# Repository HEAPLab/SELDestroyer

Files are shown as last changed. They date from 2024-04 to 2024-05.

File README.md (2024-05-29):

This README is a WIP.

# SEL Destroyer
This repository contains the hardware, firmware and software files of the
**SEL Destroyer** board, which is an electronic device to detect and destroy
the Single Event Latches (SELs) happening during SEE testing of electronic
components (radiation testing, laser-based testing, etc.).

The SEL destroyer can be also used as a normal voltage, current, or power monitoring device.

## Features
...

## Repository structure
- The `hardware` directory contains the KiCad files
  - See the hardware readme (WIP)
- The `firmware` directory contains the MPLAB X project (XC8 compiler) to program the PIC microcontroller
  - See the firmware readme (WIP)
- The `software` directory contains the host software (PC-side)
  - Check the software [README](software/README.md)

## License
MIT license, see the [LICENSE](LICENSE) file.

## Acknowledgments

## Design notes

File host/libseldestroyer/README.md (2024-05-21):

## libseldestroyer

TODO

### Thread safety
This library is partially thread-safe:
- You can call any function from different thread with the exception of...
- Calling the same function from two threads may bring to unexpected de-synchronization of the value. For instance, two concurrent access to V/I function may result in returing the same values for both calls

TODO

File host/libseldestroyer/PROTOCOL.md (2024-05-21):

Protocol description
====================

All the messages (in both directions) begin with the character `$`. If any
error occurs, each side must wait for the following `$` character.
All the commands are terminated with `\n` character.

Device -> Host
--------------
- `$P`: Pong
- `$V,SXXXXX`: voltage reading, XXXXX in mV
- `$I,SXXXXX`: current reading, XXXXX in mA
- `$N,+XXX`: number of SELs detected
- `$S`: SEL detected (XXXXX = max current in mA)
- `$CL,XXXXX`: current limiter set value, XXXXX in mA
- `$CH,XXXXX`: current limiter hold time value, XXXXX in 100-us (i.e., XXXXXX=1
  means 100us, XXXXX=20000 means 2 seconds. Max allowed value 4 seconds)
- `$CM,XXXXX`: average mode
- `$CO,X`: current output status: 0 - always OFF, 1 - always ON, A - auto
- `$E`: protocol error / overflow
- `$*`: done (any request)

Host -> Device
--------------
- `$P`: Ping
- `$A`: Ask for V/I instant readings
- `$N`: Ask for number of SELs
- `$R`: Reset number of SELs
- `$?`: Ask for current configs
- `$CL,XXXXX`: Configure limiter set value,  XXXXX in mA
- `$CH,XXXXX`: Configure limiter hold time value in 100-us (i.e., XXXXXX=1
  means 100us, XXXXXX=100000 means 10 seconds)
- `$CM,X`: Configure average mode of the INA233
- `$CO,X`:  Set output mode: 0 - always OFF, 1 - always ON, A - auto

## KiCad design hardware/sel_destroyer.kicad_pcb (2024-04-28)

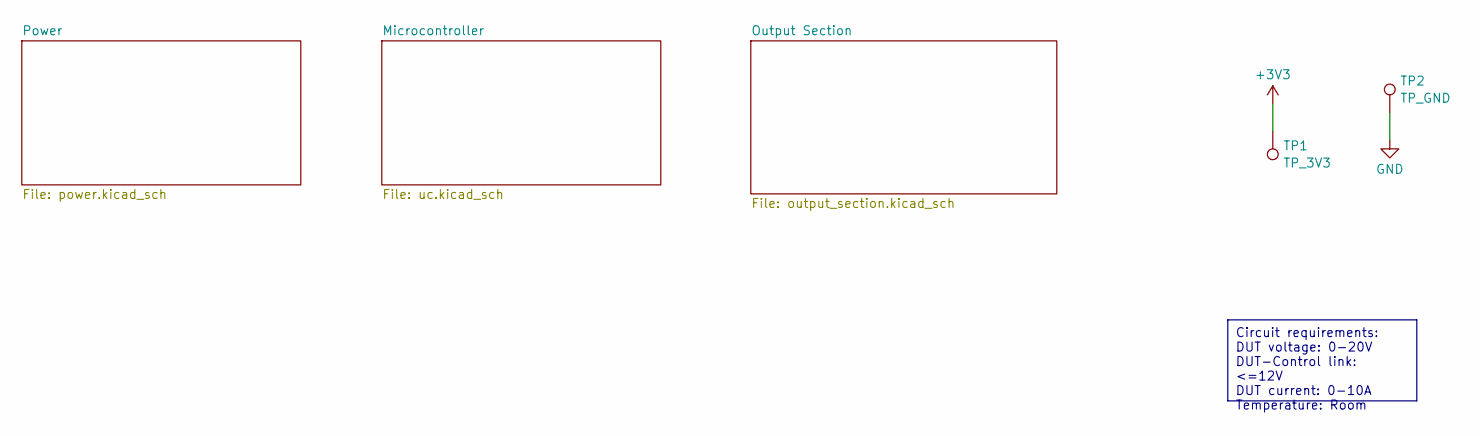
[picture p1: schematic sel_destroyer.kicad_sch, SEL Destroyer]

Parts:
TP1: TP_3V3; TestPoint_Loop_D1.80mm_Drill1.0mm_Beaded
TP2: TP_GND; TestPoint_Loop_D1.80mm_Drill1.0mm_Beaded

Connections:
+3V3: TP1.1; also elsewhere on the board
GND: TP2.1; also elsewhere on the board

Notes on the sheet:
Circuit requirements: DUT voltage: 0-20V DUT-Control link: <=12V DUT current: 0-10A Temperature: Room

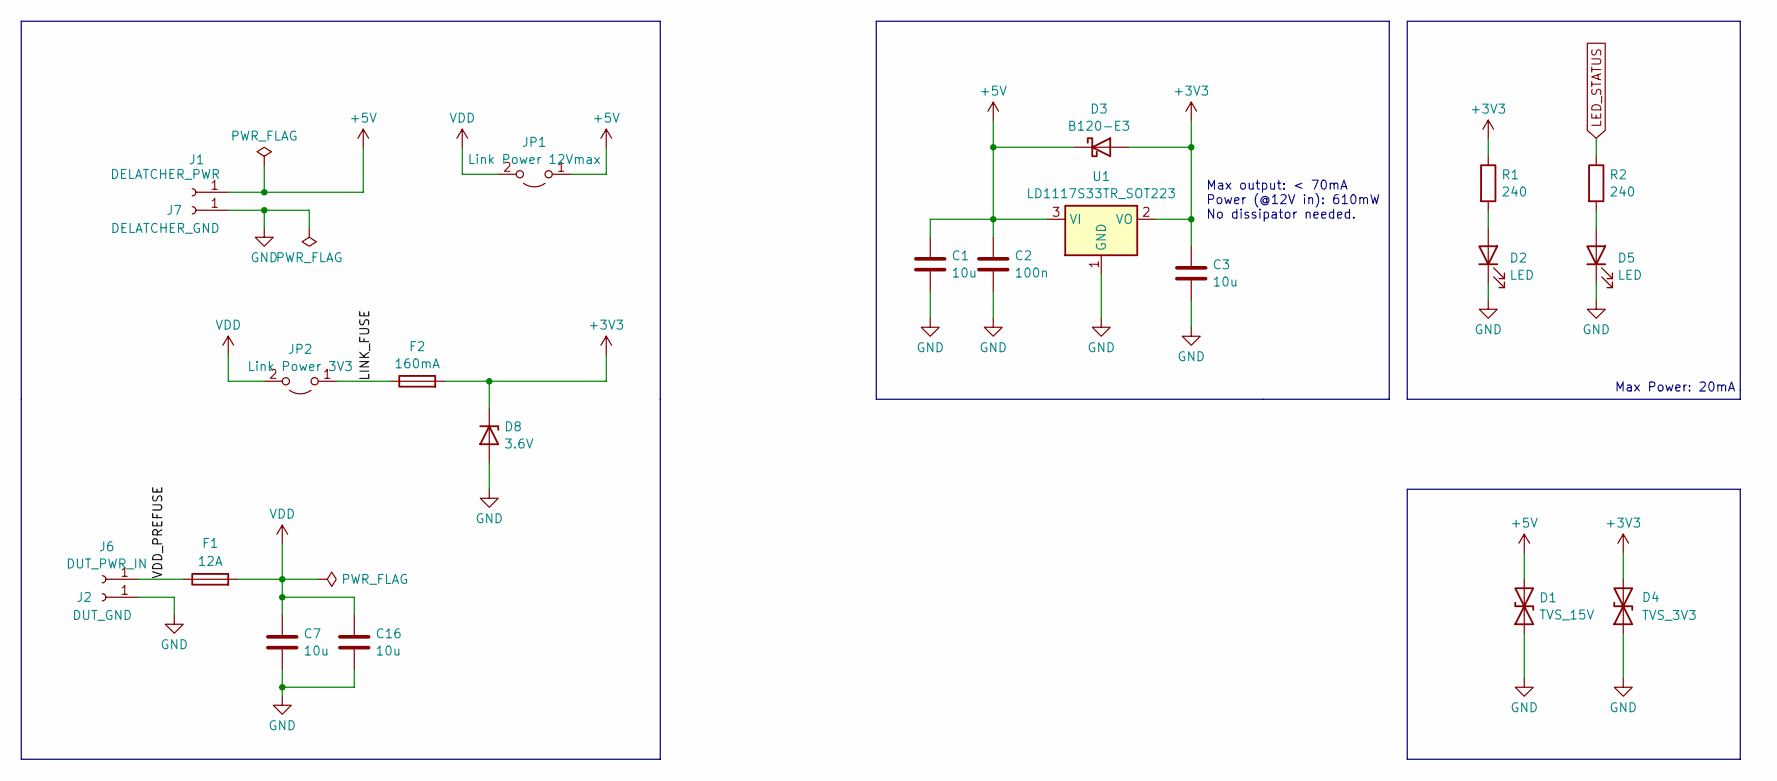
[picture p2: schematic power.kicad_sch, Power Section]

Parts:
C1, C3: 10u; C_0805_2012Metric_Pad1.18x1.45mm_HandSolder
C2: 100n; C_0805_2012Metric_Pad1.18x1.45mm_HandSolder
C7, C16: 10u; C_1206_3216Metric_Pad1.33x1.80mm_HandSolder
D1: TVS_15V; D_0603_1608Metric_Pad1.05x0.95mm_HandSolder
D2, D5: LED; LED_0805_2012Metric_Pad1.15x1.40mm_HandSolder
D3: B120-E3; D_SMA
D4: TVS_3V3; D_0603_1608Metric_Pad1.05x0.95mm_HandSolder
D8: 3.6V; D_SMB_Handsoldering
F1: 12A; Fuse_1206_3216Metric_Pad1.42x1.75mm_HandSolder
F2: 160mA; Fuse_1206_3216Metric_Pad1.42x1.75mm_HandSolder
J1: DELATCHER_PWR; CT3151
J2: DUT_GND; CT3151
J6: DUT_PWR_IN; CT3151
J7: DELATCHER_GND; CT3151
JP1: Link Power 12Vmax; PinHeader_1x02_P2.54mm_Vertical
JP2: Link Power 3V3; PinHeader_1x02_P2.54mm_Vertical
R1, R2: 240; R_0805_2012Metric_Pad1.20x1.40mm_HandSolder
U1: LD1117S33TR_SOT223; SOT-223-3_TabPin2

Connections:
+3V3: C3.1, D3.2 (A), D4.2 (A2), D8.1 (K), F2.2, R1.1, U1.2 (VO); also elsewhere on the board
+5V: C1.1, C2.1, D1.2 (A2), D3.1 (K), J1.1, JP1.1 (A), U1.3 (VI)
/Power/LINK_FUSE: F2.1, JP2.1 (A)
/Power/VDD_PREFUSE: F1.1, J6.1
GND: C1.2, C2.2, C3.2, C7.2, C16.2, D1.1 (A1), D2.1 (K), D4.1 (A1), D5.1 (K), D8.2 (A), J2.1, J7.1, U1.1 (GND); also elsewhere on the board
LED_STATUS: R2.1; also elsewhere on the board
unnamed: D2.2 (A), R1.2
unnamed: D5.2 (A), R2.2
VDD: C7.1, C16.1, F1.2, JP1.2 (B), JP2.2 (B); also elsewhere on the board

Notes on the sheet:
Max Power: 20mA
Max output: < 70mA Power (@12V in): 610mW No dissipator needed.

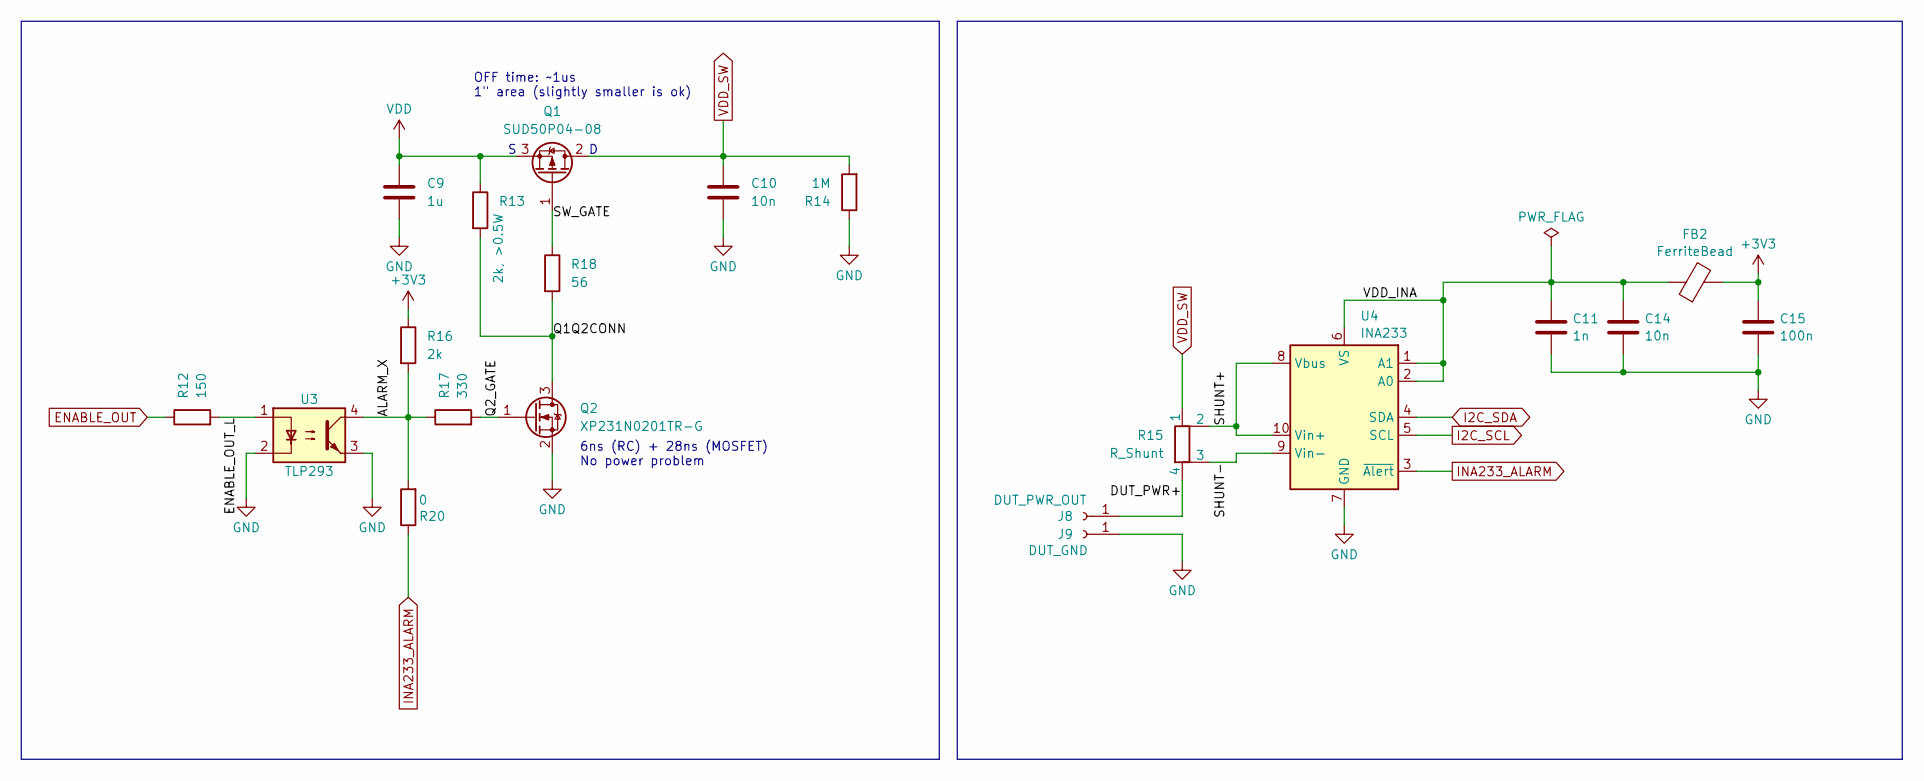
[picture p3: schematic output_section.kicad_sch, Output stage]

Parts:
C9: 1u; C_0805_2012Metric_Pad1.18x1.45mm_HandSolder
C10, C14: 10n; C_0805_2012Metric_Pad1.18x1.45mm_HandSolder
C11: 1n; C_0805_2012Metric_Pad1.18x1.45mm_HandSolder
C15: 100n; C_0805_2012Metric_Pad1.18x1.45mm_HandSolder
FB2: FerriteBead; L_0805_2012Metric_Pad1.15x1.40mm_HandSolder
J8: DUT_PWR_OUT; CT3151
J9: DUT_GND; CT3151
Q1: SUD50P04-08; TO-252-2
Q2: XP231N0201TR-G; SOT-23
R12: 150; R_0805_2012Metric_Pad1.20x1.40mm_HandSolder
R13: 2k, >0.5W; R_0805_2012Metric_Pad1.20x1.40mm_HandSolder
R14: 1M; R_0805_2012Metric_Pad1.20x1.40mm_HandSolder
R15: R_Shunt; R_Shunt_Vishay_WSK2512_6332Metric_T2.21mm
R16: 2k; R_0805_2012Metric_Pad1.20x1.40mm_HandSolder
R17: 330; R_0805_2012Metric_Pad1.20x1.40mm_HandSolder
R18: 56; R_0805_2012Metric_Pad1.20x1.40mm_HandSolder
R20: 0; R_0805_2012Metric_Pad1.20x1.40mm_HandSolder
U3: TLP293; SOIC-4_4.55x2.6mm_P1.27mm
U4: INA233; VSSOP-10_3x3mm_P0.5mm

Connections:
+3V3: C15.1, FB2.2, R16.1; also elsewhere on the board
/Output Section/DUT_PWR+: J8.1, R15.4
/Output Section/ENABLE_OUT_L: R12.2, U3.1
/Output Section/Q1Q2CONN: Q2.3 (D), R13.2, R18.2
/Output Section/Q2_GATE: Q2.1 (G), R17.2
/Output Section/SHUNT+: R15.2, U4.8 (Vbus), U4.10 (Vin+)
/Output Section/SHUNT-: R15.3, U4.9 (Vin-)
/Output Section/SW_GATE: Q1.1 (G), R18.1
/Output Section/VDD_INA: C11.1, C14.1, FB2.1, U4.1 (A1), U4.2 (A0), U4.6 (VS)
ENABLE_OUT: R12.1; also elsewhere on the board
GND: C9.2, C10.2, C11.2, C14.2, C15.2, J9.1, Q2.2 (S), R14.1, U3.2, U3.3, U4.7 (GND); also elsewhere on the board
I2C_SCL: U4.5 (SCL); also elsewhere on the board
I2C_SDA: U4.4 (SDA); also elsewhere on the board
INA233_ALARM: R20.1, U4.3 (~Alert); also elsewhere on the board
unnamed: R16.2, R17.1, R20.2, U3.4
VDD: C9.1, Q1.3 (S), R13.1; also elsewhere on the board
VDD_SW: C10.1, Q1.2 (D), R14.2, R15.1

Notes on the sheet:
OFF time: ~1us 1" area (slightly smaller is ok)
6ns (RC) + 28ns (MOSFET) No power problem

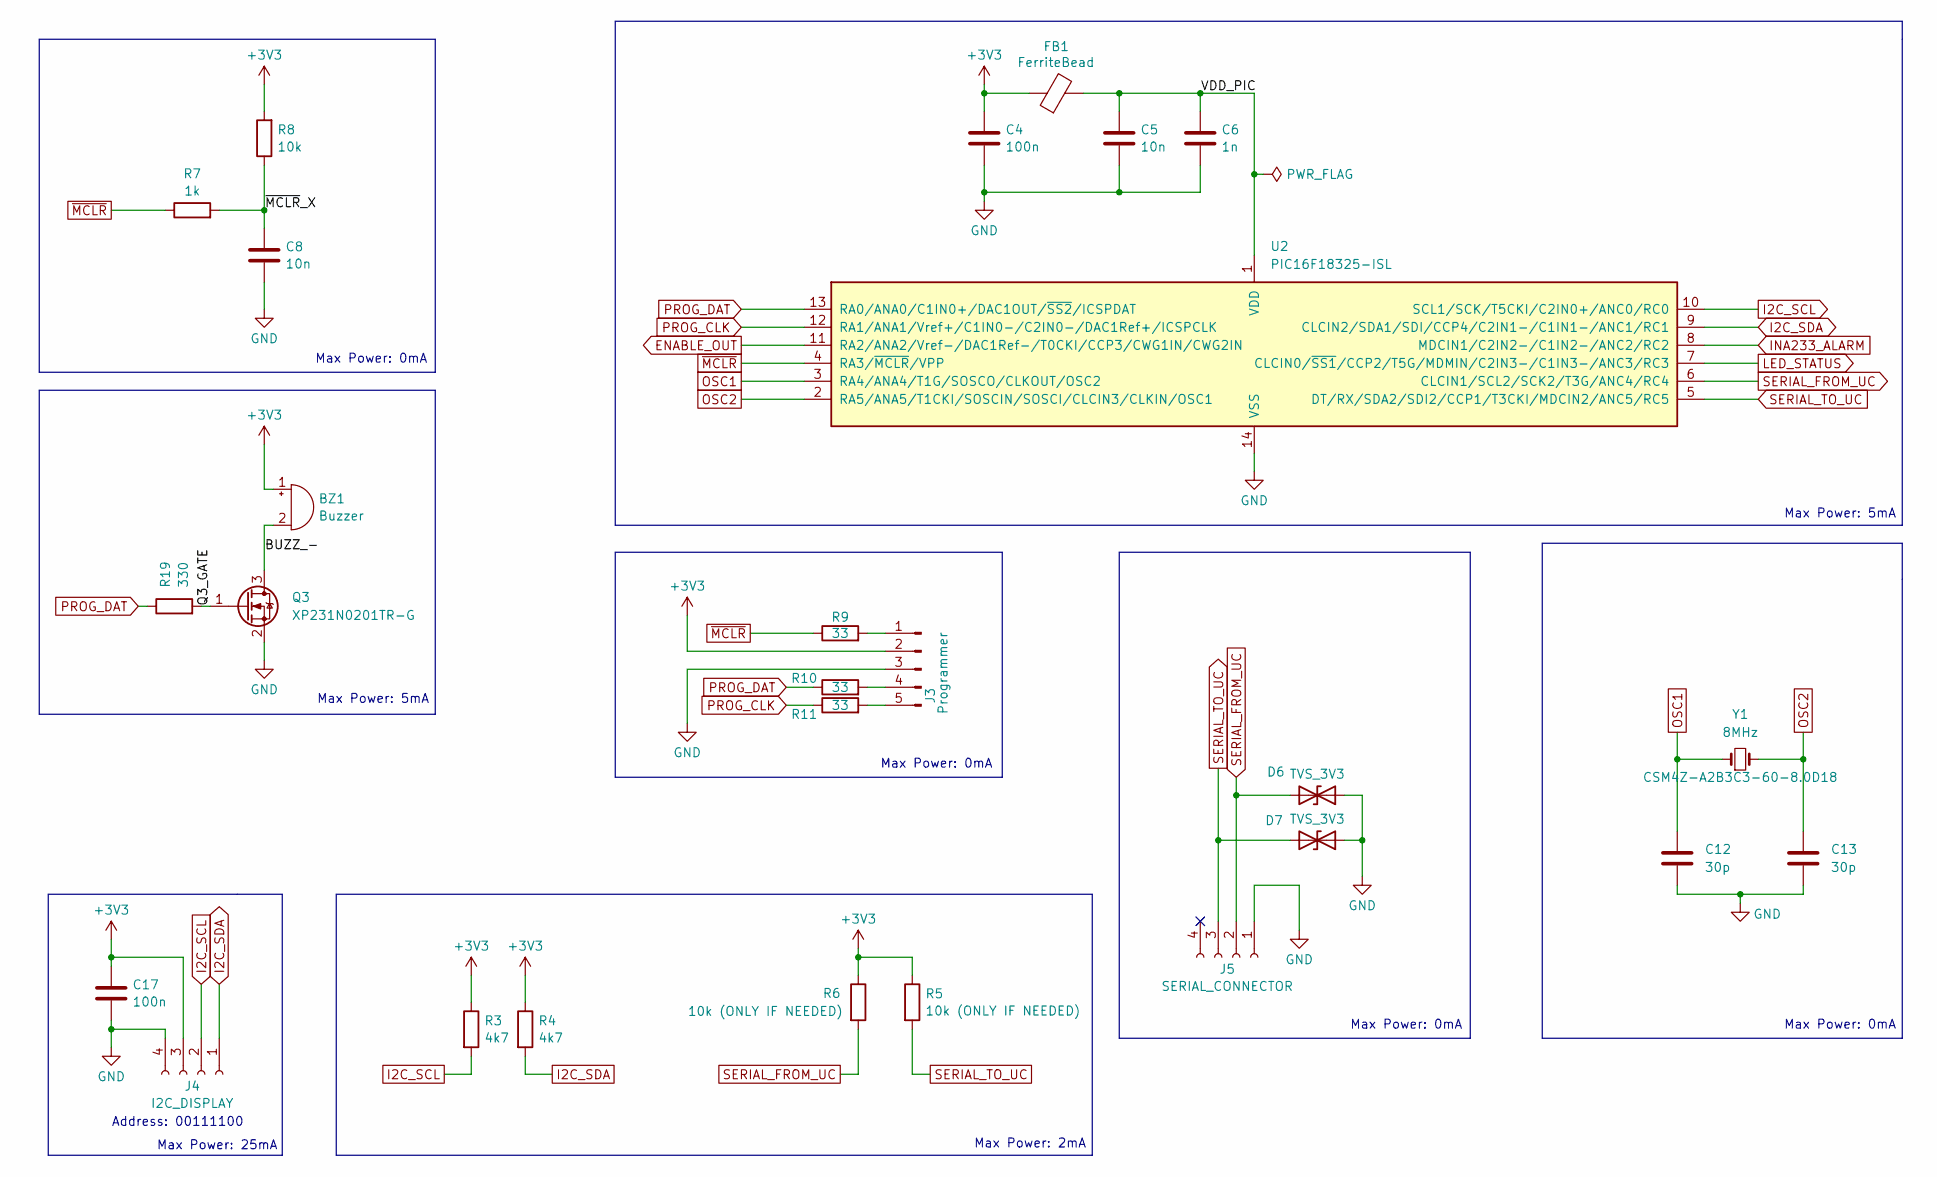
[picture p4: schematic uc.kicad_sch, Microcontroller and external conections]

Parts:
BZ1: Buzzer; Buzzer_CUI_CPT-9019S-SMT
C4, C17: 100n; C_0805_2012Metric_Pad1.18x1.45mm_HandSolder
C5, C8: 10n; C_0805_2012Metric_Pad1.18x1.45mm_HandSolder
C6: 1n; C_0805_2012Metric_Pad1.18x1.45mm_HandSolder
C12, C13: 30p; C_0805_2012Metric_Pad1.18x1.45mm_HandSolder
D6, D7: TVS_3V3; D_0603_1608Metric_Pad1.05x0.95mm_HandSolder
FB1: FerriteBead; L_0805_2012Metric_Pad1.15x1.40mm_HandSolder
J3: Programmer; PinHeader_1x05_P2.54mm_Vertical
J4: I2C_DISPLAY; PinSocket_1x04_P2.54mm_Vertical
J5: SERIAL_CONNECTOR; PinSocket_1x04_P2.54mm_Horizontal
Q3: XP231N0201TR-G; SOT-23
R3, R4: 4k7; R_0805_2012Metric_Pad1.20x1.40mm_HandSolder
R5, R6: 10k (ONLY IF NEEDED); R_0805_2012Metric_Pad1.20x1.40mm_HandSolder
R7: 1k; R_0805_2012Metric_Pad1.20x1.40mm_HandSolder
R8: 10k; R_0805_2012Metric_Pad1.20x1.40mm_HandSolder
R9, R10, R11: 33; R_0805_2012Metric_Pad1.20x1.40mm_HandSolder
R19: 330; R_0805_2012Metric_Pad1.20x1.40mm_HandSolder
U2: PIC16F18325-ISL; SOIC-14_3.9x8.7mm_P1.27mm
Y1: 8MHz; Crystal_SMD_HC49-SD

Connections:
+3V3: BZ1.1 (+), C4.1, C17.1, FB1.1, J3.2, J4.3, R3.1, R4.1, R5.1, R6.1, R8.2; also elsewhere on the board
/Microcontroller/BUZZ_-: BZ1.2 (-), Q3.3 (D)
/Microcontroller/Q3_GATE: Q3.1 (G), R19.2
/Microcontroller/VDD_PIC: C5.1, C6.1, FB1.2, U2.1 (VDD)
/Microcontroller/~MCLR_X: C8.1, R7.2, R8.1
ENABLE_OUT: U2.11 (RA2/ANA2/Vref-/DAC1Ref-/T0CKI/CCP3/CWG1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); also elsewhere on the board
GND: C4.2, C5.2, C6.2, C8.2, C12.2, C13.2, C17.2, D6.1 (A1), D7.1 (A1), J3.3, J4.4, J5.1, Q3.2 (S), U2.14 (VSS); also elsewhere on the board
I2C_SCL: J4.2, R3.2, U2.10 (SCL1/SCK/T5CKI/C2IN0+/ANC0/RC0); also elsewhere on the board
I2C_SDA: J4.1, R4.2, U2.9 (CLCIN2/SDA1/SDI/CCP4/C2IN1-/C1IN1-/ANC1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); also elsewhere on the board
INA233_ALARM: U2.8 (MDCIN1/C2IN2-/C1IN2-/ANC2/RC2); also elsewhere on the board
LED_STATUS: U2.7 (CLCIN0/~SS1/CCP2/T5G/MDMIN/C2IN3-/C1IN3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); also elsewhere on the board
unnamed: J3.1, R9.2
unnamed: J3.4, R10.2
unnamed: J3.5, R11.2
OSC1: C12.1, U2.3 (RA4/ANA4/T1G/SOSCO/CLKOUT/OSC2), Y1.1
OSC2: C13.1, U2.2 (RA5/ANA5/T1CKI/SOSCIN/SOSCI/CLCIN3/CLKI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), Y1.2
PROG_CLK: R11.1, U2.12 (RA1/ANA1/Vref+/C1IN0-/C2IN0-/DAC1Ref+/I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)
PROG_DAT: R10.1, R19.1, U2.13 (RA0/ANA0/C1IN0+/DAC1OUT/~SS2/ICSPDAT)
SERIAL_FROM_UC: D6.2 (A2), J5.2, R6.2, U2.6 (CLCIN1/SCL2/SCK2/T3G/ANC4/RC4)
SERIAL_TO_UC: D7.2 (A2), J5.3, R5.2, U2.5 (DT/RX/SDA2/SDI2/CCP1/T3CKI/MDCIN2/ANC5/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)
~MCLR: R7.1, R9.1, U2.4 (RA3/~MCLR/VPP)

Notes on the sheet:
Max Power: 2mA
Max Power: 0mA
Address: 00111100
Max Power: 5mA
Max Power: 25mA

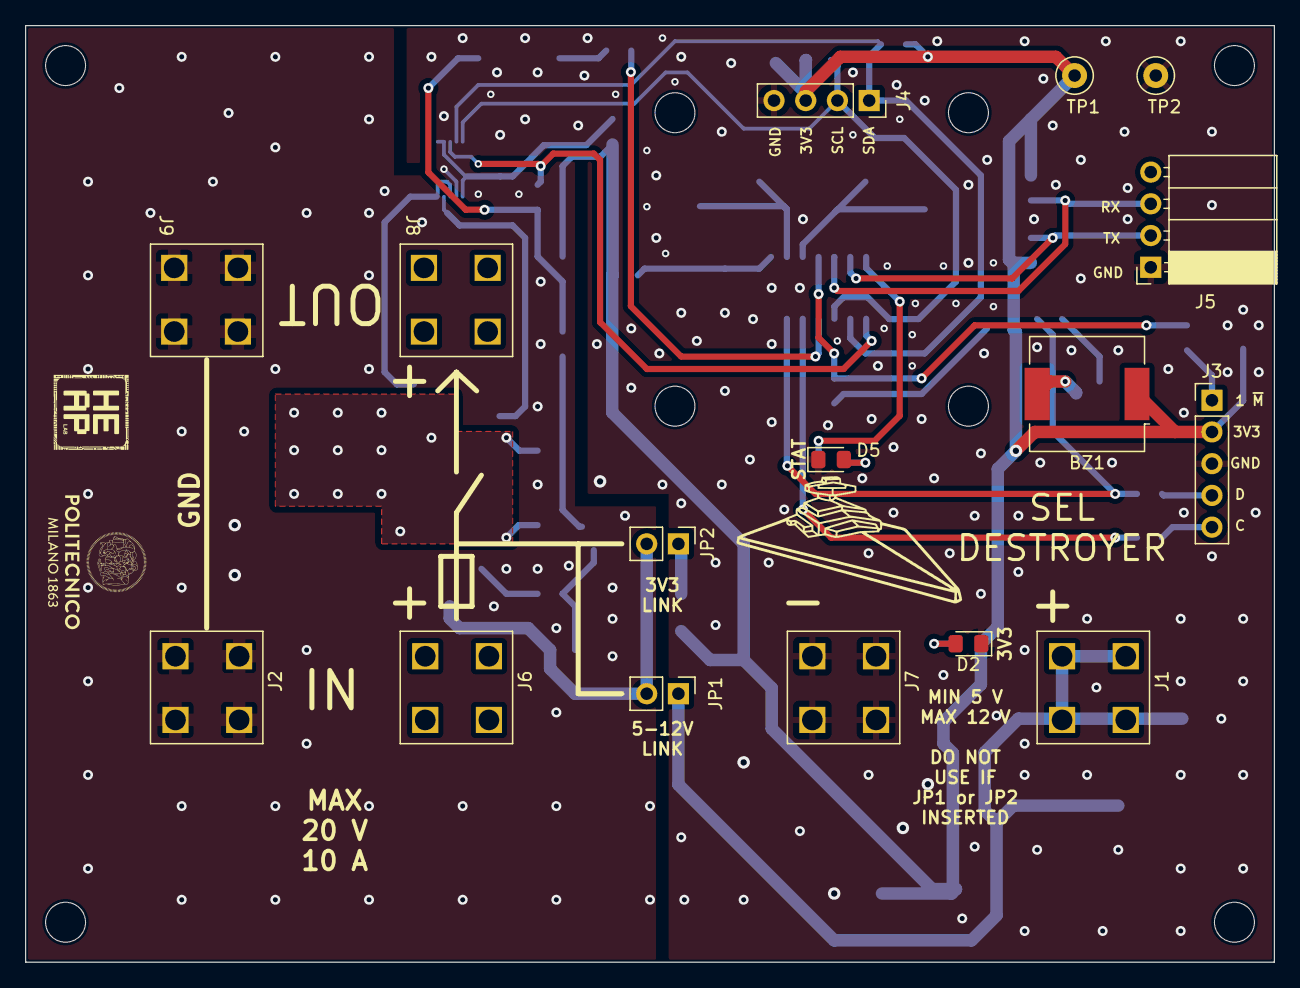
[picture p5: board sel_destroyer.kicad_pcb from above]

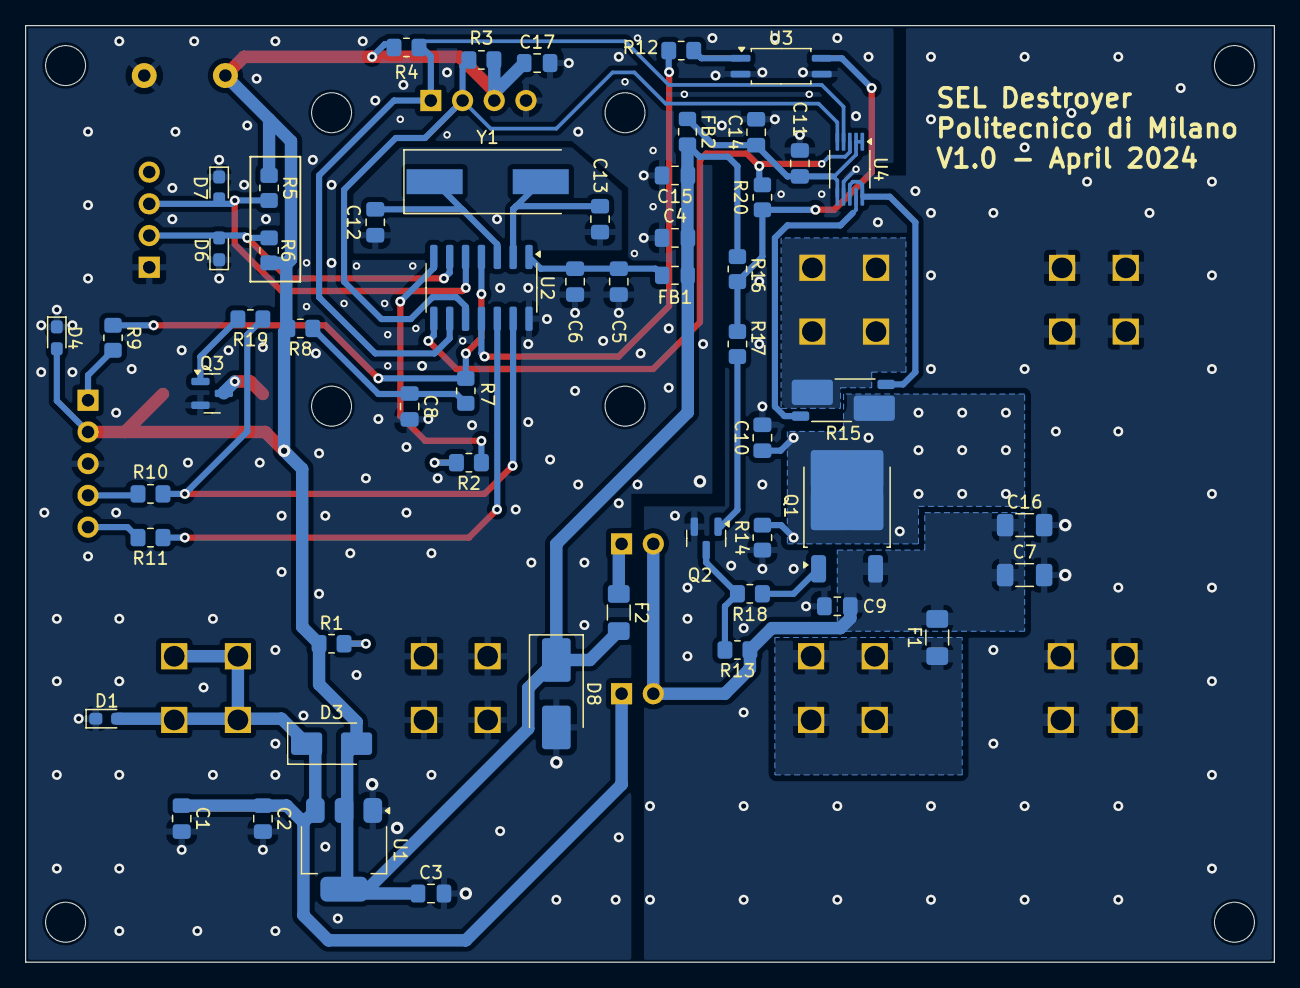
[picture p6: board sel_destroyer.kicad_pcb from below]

Board: 2 copper layers, 100.0 x 75.0 mm, 71 parts (55 on the bottom side), 37 nets.

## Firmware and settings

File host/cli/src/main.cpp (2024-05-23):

#include "libseldestroyer.h"

#include "options.hpp"

#include <chrono>
#include <memory>
#include <iostream>

static lsd_obj_t lobj;

static void ret_checker(lsd_return_val_t ret) {
    if(ret != LSD_OK) {
        std::cerr << "Error! " << std::endl
                  << "Code:    " << (int) ret << std::endl
                  << "Details: " << lsd_get_error(lobj) << std::endl;

        throw std::exception();
    }
}

static void perform_connect(const std::string &device_name) {
    lsd_return_val_t ret = lsd_connect(lobj, device_name.c_str());
    ret_checker(ret);
}

static void perform_readVI() {
    lsd_readings_t out;
    lsd_return_val_t ret = lsd_get_readings(lobj, &out);
    ret_checker(ret);
    std::cout << "Voltage (V): " << out.V << std::endl;
    std::cout << "Current (A): " << out.I << std::endl;
    std::cout << "Power   (W): " << out.V * out.I << std::endl;
}

static void perform_getSEL() {
    unsigned int out;
    lsd_return_val_t ret = lsd_get_SEL_count(lobj, &out);
    ret_checker(ret);
    std::cout << "SEL counter: " << out << std::endl;
}

static void perform_resetSEL() {
    unsigned int out;
    lsd_return_val_t ret = lsd_reset_SEL_count(lobj);
    ret_checker(ret);
    std::cout << "RESET SEL OK." << std::endl;
}

static void perform_getCONFIG() {
    lsd_config_t out;
    lsd_return_val_t ret = lsd_get_config(lobj, &out);
    ret_checker(ret);
    std::cout << "Max current              (A): " << out.sel_curr_max_A << std::endl;
    std::cout << "Hold time               (us): " << out.sel_hold_time_us << std::endl;
    std::cout << "Number of averages:           " << out.avg_num << std::endl;
    std::cout << "Voltage conversion time (us): " << out.voltage_conv_time << std::endl;
    std::cout << "Current conversion time (us): " << out.current_conv_time << std::endl;
    std::cout << "Output state:                 ";
    switch (out.output_status) {
        case LSD_OUTPUT_STATUS_OFF: std::cout  << "OFF"; break;
        case LSD_OUTPUT_STATUS_ON: std::cout   << "ON"; break;
        case LSD_OUTPUT_STATUS_AUTO: std::cout << "AUTO"; break;
        default: std::cout << "UNKONWN"; break;
    }
    std::cout << std::endl;

}

void perform_set_output(lsd_output_status_t output_state) {

    lsd_return_val_t ret = lsd_set_output(lobj, output_state);
    ret_checker(ret);

    std::cout << "Output setting updated." << std::endl;
}

void perform_set_config(std::optional<float> arg_max_I, std::optional<unsigned int> arg_hold_time, std::optional<lsd_avg_t> arg_avg_num, std::optional<lsd_conv_t> arg_voltage_conv_time, std::optional<lsd_conv_t> arg_current_conv_time) {

    lsd_config_t out;
    lsd_return_val_t ret = lsd_get_config(lobj, &out);
    ret_checker(ret);

    if(arg_max_I) out.sel_curr_max_A = *arg_max_I;
    if(arg_hold_time) out.sel_hold_time_us = *arg_hold_time;
    if(arg_avg_num) out.avg_num = *arg_avg_num;
    if(arg_voltage_conv_time) out.voltage_conv_time = *arg_voltage_conv_time;
    if(arg_current_conv_time) out.current_conv_time = *arg_current_conv_time;

    ret = lsd_set_config(lobj, &out);
    ret_checker(ret);

    std::cout << "Config setting updated." << std::endl;
}

extern "C" void go_monitor_sel_cb(void) {
    auto msUNIX = std::chrono::duration_cast<std::chrono::milliseconds>(std::chrono::system_clock::now().time_since_epoch()).count();

    std::cout << "SEL at=" << msUNIX/1000 << '.' << msUNIX%1000 << std::endl;
}

void go_monitor_sel() {

    lsd_register_sel_callback(lobj, go_monitor_sel_cb);

    lsd_wait(lobj);

}

int main(int argc, const char* argv[]) {

    try {
        seldestroyer::Options opt(argc, argv);

        if(opt.arg_debug) {
            lsd_debug_mode(true);
        }

        lobj = lsd_init();

        perform_connect(opt.arg_device);

        if(opt.arg_readVI)    perform_readVI();
        if(opt.arg_getSEL)    perform_getSEL();
        if(opt.arg_resetSEL)  perform_resetSEL();
        if(opt.arg_getCONFIG) perform_getCONFIG();
        if(opt.arg_output)    perform_set_output(*opt.arg_output);

        if (opt.arg_max_I || opt.arg_hold_time || opt.arg_avg_num 
        || opt.arg_voltage_conv_time || opt.arg_current_conv_time
        ) {
            perform_set_config(opt.arg_max_I, opt.arg_hold_time, opt.arg_avg_num, opt.arg_voltage_conv_time, opt.arg_current_conv_time);
        }

        if(opt.arg_monitorSEL) go_monitor_sel();

        lsd_close(lobj);
        
    } catch(...) {
        if(lobj) {
            lsd_close(lobj);
        }
        return 1;
    }
    return 0;
}

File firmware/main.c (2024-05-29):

/*
 * File:   main.c
 * Author: federico
 *
 * Created on April 7, 2024, 1:05 AM
 */


#include "config.h"
#include "system.h"
#include "destroyer.h"
#include "display.h"
#include "i2c.h"
#include "ssd1306.h"
#include "ina233.h"
#include "protocol.h"

ina233_res_t main_current_readings;


void main(void) {

    system_io_init();
    
    IO_OUTPUT_DIS_SET(1);   // Disable output for safety
    IO_BUZZER_SET(0);       // Disable buzzer (we have an hardware problem with it)

    IO_LED_STATUS_SET(1);
    system_primary_init();
    IO_LED_STATUS_SET(0);

    for (int i=0; i<3; i++) {        
        IO_LED_STATUS_SET(1);
        __delay_ms(50);
        
        IO_LED_STATUS_SET(0);
        __delay_ms(50);
    }
    
    i2c_init();

    ina233_init();
    
    if(!ina233_test()) {
        throw_fatal_exception();
    }
        
    destroyer_init();
    SSD1306_init();
    
    display_init_sequence();
        
    while(1) {

        if(destroyer_data.out_status != 0xAA || destroyer_data.T_hold_us >= 20) {
            main_current_readings = ina233_read();
        }
        
        destroyer_update();
        display_update();
        protocol_update();
        
        CLRWDT();
    }
    
    return;
}

void __attribute__((noreturn)) throw_fatal_exception (void) {
    while(1) {
        IO_LED_STATUS_SET(1);
    }
}

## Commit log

2024-04-28 [Host] Implemented class flow down to serial port
2024-04-28 [Hardware] Import from old repository
    [output_section.kicad_sch, power.kicad_sch, sel_destroyer.kicad_pcb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]
2024-05-05 [Firmware] I2C implementation
2024-05-11 [Firmware] Working RX/TX serial with interrupts
2024-05-20 [Firmware] Various fixes (mainly overflow in the display visualization)
    [i2c.c, main.c]
2024-05-21 [Firmware] Fix data size of some configuration items and messages
    [system.c]
2024-05-21 [Firmware/Host] First working full flow (but slow reset SEL response)
    [ina233.c, main.c]
2024-05-23 [Host] [Lib] Add version and fix ADC config bit composition
    [libseldestroyer.cpp]
2024-05-23 [Firmware] Fix MFR send to device
    [libseldestroyer.cpp]
2024-05-29 [Firmware] Minor fixes around to improve reliability
    [system.c]
